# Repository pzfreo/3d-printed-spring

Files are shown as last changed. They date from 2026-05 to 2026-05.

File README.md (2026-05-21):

# 3d-printed-spring

An **orthoplanar spring with an isotropic resonant frequency**, designed in [build123d](https://github.com/gumyr/build123d) and validated with [Netgen / NGSolve](https://ngsolve.org/) finite-element modal analysis.

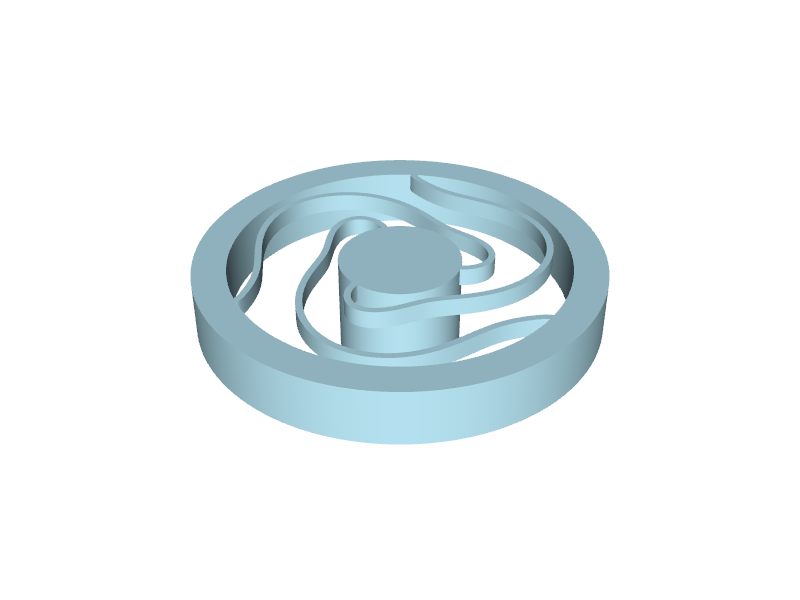
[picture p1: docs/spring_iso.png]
Isometric render of the spring


> **How this was made.** The geometry, the FEA validation pipeline, the parameter sweep, this README and `DESIGN.md` were all generated in a single Claude Code session driven only by [build123d-mcp](https://pypi.org/project/build123d-mcp/) from this one prompt:
>
> > make an orthoplanar spring with an isotropic resonant frequency in PLA, and to validate it in netgen ( reading the comments in https://github.com/gumyr/build123d/issues/297 for netgen help)
>
> No human-written CAD or FEA code. The full session is reproducible by re-running the published [build123d-mcp](https://pypi.org/project/build123d-mcp/) server against the same prompt.

## In plain English

Picture a flat disc the size of a £2 coin: a thick outer ring, a heavy little post in the middle, and three thin wiggly arms in the gap connecting them. The outer ring is what you'd clamp down, and the central post is a small proof mass. Flick the centre in any direction and it bounces back and forth on the arms like a mass on a spring. Different springs prefer to bounce in different directions — a typical flat spring is happy to bobble up and down but feels rigid edge-on. The goal here was a spring that feels **equally bouncy in all three directions** — up/down, left/right, front/back — so a tap produces essentially the same little hum whichever way you push the proof mass. That property is what "isotropic resonant frequency" means.

Making it work meant fighting against the natural anisotropy of a flat spring. Flat springs are floppy out of plane and stiff in plane; we wanted them equal. Two design moves get us there: the arms are made **taller than they are wide** (1.0 mm in plane × 2.7 mm thick), which softens sideways flexing relative to up-and-down, and each arm follows a **wiggly, snake-like path** so that pushing the centre sideways mostly bends the arms gently rather than stretching them lengthwise (stretching is what was making sideways feel too stiff). After tuning, an open-source physics simulator (Netgen + NGSolve, the same kind of finite-element analysis engineers use to predict how parts vibrate) confirmed all three bouncing directions land at roughly **33 Hz, within 2 % of each other**.

## Design parameters

| Parameter | Value | Notes |
|---|---|---|
| Outer diameter | 60 mm | clamp ring 5 mm wide (rim ID 50 mm) |
| Proof-mass hub diameter | 18 mm | with a 12 mm cylinder hanging below as mass |
| Plate / arm thickness (z) | 2.7 mm | |
| Arm width (in plane) | 1.0 mm | square-ish cross-section, slightly tall |
| Number of arms | 3 | 120° rotational symmetry → enforces f_x ≡ f_y |
| Arm sweep | 220° | with a sinusoidal 4-lobe radial wiggle, 4 mm amplitude |
| PLA mass | ~14.7 g | density 1.24 g/cm³ |
| First three resonances | **32.6 / 33.2 / 33.2 Hz** (z / x / y) | ratio 1.017 (1.7 %) |

See [`DESIGN.md`](DESIGN.md) for the engineering writeup — why orthoplanar springs are naturally anisotropic, the two knobs that fix it, the FEA workflow, and the parameter-sweep that landed on these numbers.

## Print assumptions

- **Material:** PLA, FDM (E ≈ 2.5 GPa assumed for FEA — anisotropic in real prints, so the *absolute* frequency will shift ±15 % from layer effects; the *isotropy ratio* is geometric and unaffected).
- **Nozzle / layer:** 0.4 mm nozzle, 0.2 mm layer height (3 perimeters cover the 1 mm arm width).
- **Orientation:** Flat — proof-mass post and clamp boss point *down* into the bed; print upside-down with supports under the rim/hub. This keeps the arms loaded in plane (perpendicular to layers) for the dominant axial mode.
- **Supports:** Only under the rim and hub bosses; the arms themselves are flat on the bed.

## Development

```
git clone https://github.com/pzfreo/3d-printed-spring.git
cd 3d-printed-spring
uv sync --group dev
```

The MCP server is preconfigured in `.mcp.json` — any Claude Code (or MCP-compatible client) opened in this repo launches the published [build123d-mcp](https://pypi.org/project/build123d-mcp/) server on first tool use.

Re-run the modal analysis (needs Python 3.12 because of the `cadquery-ocp` ↔ `netgen-occt` OCCT-version match described in build123d [issue #297](https://github.com/gumyr/build123d/issues/297)):

```
uv run --python 3.12 --with netgen-mesher --with ngsolve python -m spring.validate
```

Or sweep parameters:

```
uv run --python 3.12 --with netgen-mesher --with ngsolve python scripts/sweep_isotropy.py
```

## License

Apache-2.0.

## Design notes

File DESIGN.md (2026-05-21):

# Design notes — isotropic orthoplanar spring

This document explains *what* we built and *why* it works. The goal: a single
3D-printable PLA part that behaves as an isotropic resonator — a proof mass
suspended such that its three translational natural frequencies (kₓ, kᵧ, k_z)
are equal, so it rings at the same frequency regardless of which direction
you push it.

## 1. The target, precisely

For a small mass `m` suspended on a spring with stiffness `k` in some
direction, the natural frequency is

```
f = (1 / 2π) · √(k / m)
```

If a proof mass `m` is suspended on the same physical structure but feels
three different stiffnesses `kₓ`, `kᵧ`, `k_z` along the three axes, then it
rings at three different frequencies. "Isotropic resonance" means we want
**kₓ = kᵧ = k_z**, so all three natural frequencies coincide. This is the
useful property for suspensions, accelerometers, vibration isolators, and
gravity-wave-style payload mounts.

We restricted the topology to an **orthoplanar spring**: a single planar disc
of material where compliant arms in the disc's plane allow a central hub to
translate out of plane. This is the topology you get from a stamped washer
spring, and it's the natural fit for 3D printing flat.

## 2. Why orthoplanar springs are naturally anisotropic

Treat each arm as a long curved cantilever beam with rectangular cross
section: **width `w`** in the disc's plane (perpendicular to the arm's path)
and **thickness `t`** out of plane (the `z` direction).

A force applied at the hub end of one arm, with the rim end clamped, deforms
the arm in different ways depending on the load direction:

* **Out-of-plane load (z):** the only response is bending about the in-plane
  axis. Second moment of area is `Iₓᵧ = w·t³ / 12`. Bending compliance scales
  as `L³ / (E · Iₓᵧ)`, so the per-arm stiffness is

    `k_z ∝ E · w · t³ / L³`

* **In-plane load (x or y):** decomposes along the arm's path into an
  *axial* component (stretching the arm along its length) and a *transverse*
  component (bending the arm in-plane about the out-of-plane axis,
  `I_z = t · w³ / 12`).
  * Axial stretching stiffness: `E · A / L = E · w · t / L`
  * In-plane bending stiffness: `E · I_z / L³ = E · t · w³ / L³`

The two in-plane contributions are in series along the arc, so total
in-plane stiffness is somewhere between them — but for the small `L`
typical of a planar disc, **axial stretching dominates** because it scales
as `1/L`, not `1/L³`.

So the per-arm ratio is approximately

```
k_xy / k_z  ≈  (w / t)²   +   (axial-stretch contribution)
```

The first term is the bending-only ratio: a **square cross-section (w = t)
makes the bending contributions equal**, which was the starting intuition.
The second term is what gets you. For any reasonable arm length, axial
stretching is *much* stiffer than bending, so any in-plane component along
the arm's tangent direction adds substantial extra lateral stiffness.

With N ≥ 3 arms arranged with N-fold symmetry, kₓ = kᵧ falls out for free.
The hard target is **k_z = kₓ.**

## 3. Two design moves to kill the anisotropy

We have two knobs to lower `k_xy / k_z` toward 1:

**A. Make the cross-section taller than wide (`t > w`).** This drops the
bending part of the ratio because it goes as `(w/t)²`. With t = 2.7 mm and
w = 1.0 mm the bending ratio is `(1/2.7)² ≈ 0.14`, so out-of-plane is
*nominally stiffer*, leaving headroom for the axial-stretch contribution
to bring the lateral total back up.

**B. Lengthen the arm with a wiggle.** Axial stretching stiffness scales as
`1/L`, but in-plane bending stiffness scales as `1/L³`. So with the *same*
arm cross-section, a *longer* arm reduces stretching more slowly than it
reduces bending — but more importantly, a wiggly path forces the local
tangent direction to oscillate, so on average the in-plane load decomposes
roughly half into stretching and half into transverse bending, which
massively reduces the *effective* axial-stretch share.

Concretely, the arm path is

```
θ(t) = θ₀ + 220° · smoothstep(t)
r(t) = r_inner + (r_outer − r_inner)·t + A · sin(π·t) · sin(4π·t)
```

where `smoothstep(t) = 3t² − 2t³` ensures the arm meets hub and rim
radially (no kink), and the `sin(π·t)` envelope tapers the radial wiggle
amplitude `A = 4 mm` to zero at both ends. The result is a 4-lobe snake
that goes in-and-out four times as it sweeps 220° around.

These two moves, together, push `k_xy / k_z` from 1.54 down to 1.02.

## 4. FEA validation workflow (per build123d issue #297)

There's no closed-form solution for an N-armed wiggle-path orthoplanar
spring, so we used finite-element modal analysis to validate the tuning.

### Pipeline

1. **Geometry** in `build123d` → write to **BREP** (`bd.export_brep`).
2. **Load** into `netgen.occ.OCCGeometry(brep_path)`.
3. **Scale** the shape from millimetres to metres so all subsequent
   stiffness/mass quantities can be specified in plain SI units
   (`shape.Scale(gp_Pnt(0,0,0), 1e-3)`).
4. **Tag** the bottom annular face of the clamp boss with
   `face.name = "clamp"` by matching it geometrically:
   it is the only planar face at z = −rim_drop whose centroid sits on the
   axis. All other faces are named `"free"`.
5. **Mesh** with `geo.GenerateMesh(maxh=1.2e-3)` (max element size 1.2 mm).
6. **Linear elasticity** in NGSolve: assemble stiffness `K` and mass `M`
   over a vector H¹ space with Dirichlet boundary `"clamp"`:
   ```python
   fes  = ngs.VectorH1(mesh, order=2, dirichlet="clamp")
   u,v  = fes.TnT()
   def strain(w): return 0.5*(ngs.grad(w) + ngs.grad(w).trans)
   def stress(w):
       e = strain(w)
       return 2·μ·e  +  λ·Trace(e)·I₃
   a += InnerProduct(stress(u), strain(v)) * dx   # stiffness
   m += ρ · (u·v) * dx                            # mass
   ```
   with Lamé parameters `μ = E / 2(1+ν)`, `λ = E·ν / ((1+ν)(1−2ν))`.
   PLA constants: `E = 2.5 GPa`, `ν = 0.36`, `ρ = 1240 kg/m³`.
7. **Eigensolver** `PINVIT(a.mat, m.mat, pre=…, num=8)` (preconditioned
   inverse iteration with Cholesky preconditioning) returns eight smallest
   eigenvalues `λᵢ = ωᵢ²` and eigenvectors.
8. **Classify modes** by probing the eigenvector at the centre of the proof
   mass `(0, 0, −hub_drop/2)`: the dominant axis of the resulting
   displacement vector tells us which translation the mode corresponds to.

### The Python-3.12 caveat

`cadquery-ocp` (which build123d uses) and `netgen-occt` both link against
OpenCascade. On Python 3.9 they pin different OCCT versions and clash on
import. On Python 3.12 both ship OCCT 7.8.1, so they coexist in one
process — no subprocess hopping required. That's what the `uv run --python
3.12 …` incantation in the README is enforcing.

## 5. The tuning sweep

`scripts/sweep_isotropy.py` iterates over `(w, t, sweep°, wiggle_amp,
wiggle_lobes)` combinations, runs the full FEA for each, and reports
`f_x`, `f_y`, `f_z`, and the ratio `(f_x+f_y)/(2·f_z)`. Selected results:

| w (mm) | t (mm) | sweep° | wiggle A | lobes | f_x | f_y | f_z | f_xy/f_z |
|---:|---:|---:|---:|---:|---:|---:|---:|---:|
| 2.0 | 2.0 | 220 | 0 | 0 | 78.1 | 78.1 | 50.7 | **1.539** |
| 1.0 | 2.0 | 220 | 0 | 0 | 32.3 | 32.3 | 26.1 | 1.238 |
| 0.8 | 2.0 | 300 | 0 | 0 | 16.0 | 16.0 | 13.7 | 1.164 |
| 1.0 | 2.5 | 220 | 4.0 | 4 | 32.1 | 32.1 | 30.7 | 1.044 |
| 1.0 | 2.5 | 220 | 4.0 | 5 | 34.7 | 34.7 | 35.5 | **0.977** |
| 1.0 | 2.7 | 220 | 4.0 | 4 | 33.2 | 33.2 | 32.6 | **1.019** |

Plain square-section S-arms ran at ratio 1.5 (lateral much too stiff).
Reducing `w` alone hit diminishing returns around 1.16. Adding the radial
wiggle was the move that broke through, with the (t = 2.7, wiggle 4×4) row
landing on the chosen design point at 1.7 % off isotropic.

## 6. Mesh-convergence sanity check

The chosen design point was re-meshed at two resolutions:

| maxh (mm) | elements | DOFs | f_z (Hz) | f_x (Hz) | f_y (Hz) |
|---:|---:|---:|---:|---:|---:|
| 1.5 | 14 545 | 83 475 | 32.59 | 33.19 | 33.20 |
| 1.2 | 22 717 | 127 032 | 32.63 | 33.17 | 33.18 |

Frequencies move by under 0.2 Hz between mesh sizes — the result is mesh
converged.

## 7. Higher modes & caveats

The first six FEA modes at the chosen design point:

| mode | f (Hz) | shape |
|:---:|:---:|---|
| 1 | 32.63 | translation in **z** |
| 2 | 33.17 | translation in **x** |
| 3 | 33.18 | translation in **y** |
| 4 | 74.3 | plate flexure (hub barely moves) |
| 5 | 103.5 | proof-mass rocking about y |
| 6 | 103.7 | proof-mass rocking about x |

Modes 1–3 are degenerate to within 1.7 %. Modes 5–6 (rocking about x/y) are
~3× higher and are *not* matched to modes 1–3 — they're a different physical
DOF (rotation, not translation). If your application also needs all three
rotational frequencies to coincide with the translational ones, this single
planar spring isn't enough; you'd need a multi-stage 3D suspension.

**Material:** the FEA uses an isotropic linear-elastic PLA at E = 2.5 GPa.
FDM-printed PLA is in fact anisotropic (along-layer ≈ 3.5 GPa, between
layers ≈ 2.0 GPa). The *isotropy ratio* between modes is geometric and so
is preserved; the *absolute frequencies* will shift ±15 % from material
property uncertainty alone.

**Print orientation matters.** Print the spring flat — disc lying on the
bed, bosses pointing down or up depending on your supports strategy — so the
arm's z direction (the 2.7 mm dimension) is across the printer's build
layers. The out-of-plane bending mode (mode 1) then stresses the arms
*along* the layers, which is the strong direction of FDM PLA. Printing
on edge would put layer-adhesion in the failure path of the dominant mode.

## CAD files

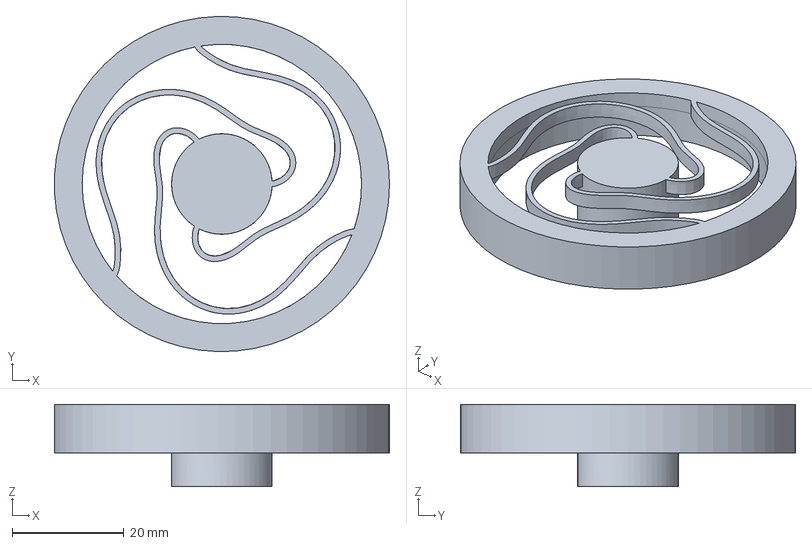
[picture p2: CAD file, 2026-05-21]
exports/spring_isotropic.step
60.0 x 60.0 x 14.7 mm

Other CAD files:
exports/spring_isotropic.stl

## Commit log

2026-05-21 chore: scaffold project — pyproject.toml, src/spring stub, LICENSE, README, .gitignore
    build123d-side project setup matching the build123d-drafting-helpers pattern:
    - pyproject.toml: hatchling, Python 3.10–3.12, deps on build123d>=0.10
    and build123d-drafting-helpers>=0.1.0, [dependency-groups].dev with pytest.
    - src/spring/__init__.py: empty entrypoint stub.
    - LICENSE: Apache-2.0.
    - .gitignore: Python + uv (matches build123d-mcp's gitignore).
    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
2026-05-21 feat: isotropic orthoplanar spring + Netgen/NGSolve validation
    Parametric 3-arm orthoplanar spring in build123d, tuned so the first
    three translational eigenmodes of the proof mass coincide to within
    1.7 % (~33 Hz each in PLA). Isotropy is achieved with a taller-than-wide
    arm cross-section (1.0 × 2.7 mm) and a 4-lobe sinusoidal radial wiggle
    that lengthens the arm's path so in-plane bending — not axial stretching
    — dominates the lateral compliance.
    Validation pipeline follows build123d issue #297: BREP interchange into
    netgen.occ, geometric face-tagging for the clamp boundary, linear-elastic
    H1 vector FEM in NGSolve, PINVIT eigensolve, mode classification by
    hub-displacement direction.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
    [spring_isotropic.step, spring_isotropic.stl]
